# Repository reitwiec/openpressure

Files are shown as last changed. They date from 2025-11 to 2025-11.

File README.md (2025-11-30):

# Open Pressure Sensing Device

Reitwiec Shandilya, Michelle Hui, Sebastian Bidegain, Joey Castillo (Cornell Tech). Carson Gundlach and Dr. David Otterburn (Weill Cornell Medicine)

A handheld, open-source instrument designed to measure tactile pressure thresholds digitally. Adapted from clinical tools like the AcroVal™ system, it applies calibrated pressure to the skin and records sensory responses for studies of nerve regeneration following reconstructive surgery.

This project supports the ongoing research of Dr. David Otterburn and Carson Gundlach at Weill Cornell Medicine, whose work in neurotization seeks to restore sensory nerve connections following breast reconstruction surgery. After mastectomy, patients often experience a loss of sensation that affects comfort, safety, and quality of life. Through surgical co-aptation of donor and recipient nerves, Dr. Otterburn’s team aims to re-establish sensory pathways; however, evaluating the success of that process has long relied on subjective or coarse analog tools.
Developed by Cornell Tech Master’s students Michelle Hui and Reitwiec Shandilya in the Cornell Tech MakerLab, this open-source device captures quantitative measurements of tactile pressure (in g/mm²). By precisely logging patient response data, it allows clinicians to objectively track sensory recovery over time, providing richer, reproducible data than traditional Semmes-Weinstein monofilaments, which only measure at discrete force intervals. Beyond reconstructive surgery, the same sensing tool could inform other clinical neurological testing and research functions, expanding open-source tools for quantifying sensation and nerve function.

The project is supported by the Cornell Tech MakerLab and is undertaken in partnership with the Open Source Hardware Association’s Open Healthware Initiative, with the support of the National Science Foundation. The goal is to create a validated, open-source alternative to proprietary devices such as the AcroVal™ Neurosensory & Motor Testing System, enabling wider adoption of transparent, reproducible clinical instrumentation across research and education.

  

## Features

- **Real-time pressure readings** via USB serial connection
- **Session management** - Create, view, and export patient sessions
- **5 readings per session** with ability to re-record any reading
- **Historical trend visualization** - Track pressure changes across sessions
- **Device calibration** - Built-in calibration workflow
- **CSV export** - Export sessions for external analysis
- **Offline operation** - All data stored locally

## Prerequisites

### Hardware
- KB2040 microcontroller (or compatible CircuitPython board)
- HX711 load cell amplifier
- Load cell sensor
- USB cable

### Software
- Node.js 18+ and npm
- macOS (for building the Mac app)

## Installation

### For Development

```bash
# Clone or copy the project
cd pressure-monitor

# Install dependencies
npm install

# Run in development mode
npm run dev
```

### Building for Distribution

```bash
# Build the Mac application
npm run build:mac

# The installer will be in the `release` folder
```

The build creates:
- `Pressure Monitor-1.0.0.dmg` - Drag-and-drop installer
- `Pressure Monitor-1.0.0-mac.zip` - Portable version

## Firmware Setup

Copy both files from the `firmware/` folder to your KB2040:

```
firmware/
├── code.py      # Main firmware (runs automatically)
└── hx711.py     # HX711 driver library
```

### Installation
1. Connect your KB2040 via USB
2. It should appear as a drive called `CIRCUITPY`
3. Copy `code.py` and `hx711.py` to the root of that drive
4. The device will automatically restart and begin running

### Pin Configuration (in code.py)
- `DT_PIN = board.GP5` - HX711 Data
- `SCK_PIN = board.GP6` - HX711 Clock  
- `BTN_PIN = board.GP16` - Button (uses internal pull-up)

## Usage

### 1. Connect the Device
1. Plug in the KB2040 via USB
2. Open Pressure Monitor
3. Select the serial port from the right panel
4. Click to connect

### 2. Calibration (First Time Setup)
1. Click "Calibrate" in the top bar
2. Long-press the device button (≥0.7 seconds) to start
3. Follow the on-screen steps:
   - Remove all load and press button
   - Place calibration mass and press button
4. Calibration is saved until device restart

### 3. Taking Readings
1. Create a new session (add optional notes)
2. Press the device button to take a reading
3. Click on an empty slot to save the reading
4. Repeat until all 5 slots are filled

### 4. Viewing History
1. Click "History" in the sidebar
2. View trend graph of average readings across sessions
3. Toggle between stress (g/mm²) and weight (g) views

### 5. Exporting Data
1. Select a session
2. Click "Export CSV" in the top bar
3. Choose save location

## Data Storage

All data is stored in `~/PressureReadings/`:
- `session_[timestamp].csv` - Reading data
- `session_[timestamp]_meta.json` - Session metadata

CSV format:
```csv
slot,timestamp,grams,stress_g_mm2
1,2025-01-15T14:30:05,45.2,117.5
2,2025-01-15T14:30:45,44.8,116.4
...
```

## Configuration

Settings are available in the connection panel:
- **Wire Diameter (mm)** - Used for stress calculation
- **Calibration Mass (g)** - Reference mass for calibration

## Troubleshooting

### Device not showing up
- Ensure the KB2040 is properly connected
- Try a different USB cable
- Check if CircuitPython is running (should show as a serial device)

### Readings not appearing
- Verify the serial connection is established (green indicator)
- Check the Device Log for error messages
- Ensure the firmware is running correctly

### Calibration issues
- Make sure to remove ALL load during tare
- Use a precise calibration mass
- Keep the sensor stable during calibration

## License

MIT License - See LICENSE file for details.

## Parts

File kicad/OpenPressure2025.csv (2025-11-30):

Designator | Qty | Value | Exclude from BOM | Footprint | LCSC
R5 | 1 | 20K |  | Resistor_SMD:R_0805_2012Metric | C4328
Q2 | 1 | SS8550 |  | Package_TO_SOT_SMD:SOT-23 | C8542
C4,C6 | 2 | 10uF |  | Capacitor_SMD:C_0805_2012Metric | C15850
R1,R2,R3,R4 | 4 | 100 |  | Resistor_SMD:R_0805_2012Metric | C17408
R7 | 1 | 10K |  | Resistor_SMD:R_0805_2012Metric | C17414
R6 | 1 | 8.2K |  | Resistor_SMD:R_0805_2012Metric | C17828
C1,C2,C3,C5,C7 | 5 | 0.1uF |  | Capacitor_SMD:C_0805_2012Metric | C49678
L1 | 1 | 3.3uH |  | Inductor_SMD:L_0603_1608Metric | C275346
J2 | 1 | MJ-3523-SMT-TR |  | CUI_MJ-3523:CUI_MJ-3523-SMT-TR | C4992553
U2 | 1 | HX711 |  | Package_SO:SOIC-16_3.9x9.9mm_P1.27mm | C6705483

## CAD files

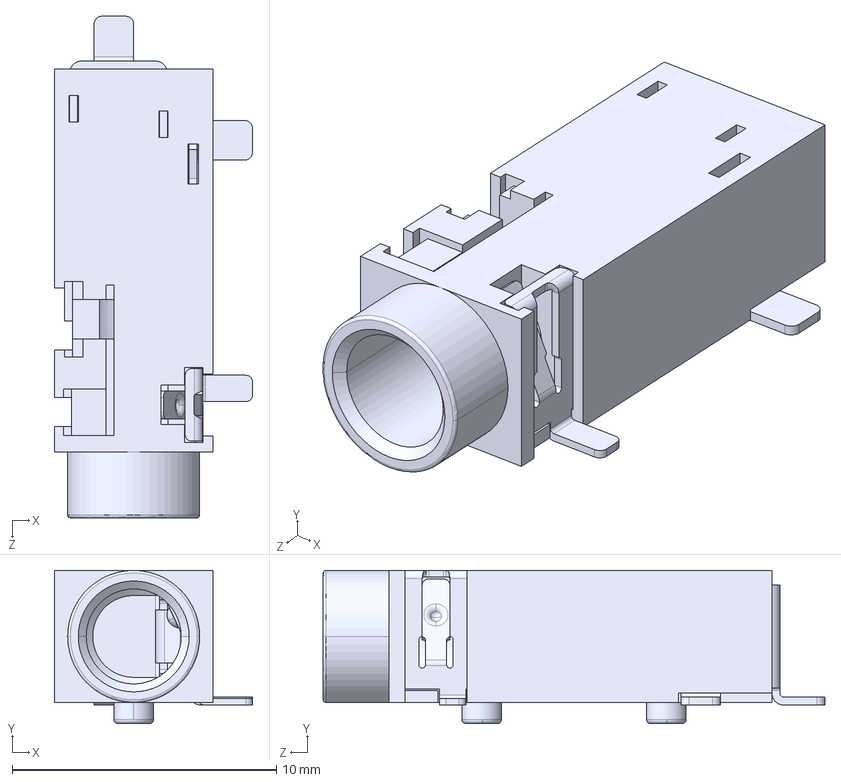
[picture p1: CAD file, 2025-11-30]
kicad/MJ-3523-SMT-TR.step
7.50 x 5.80 x 19.0 mm

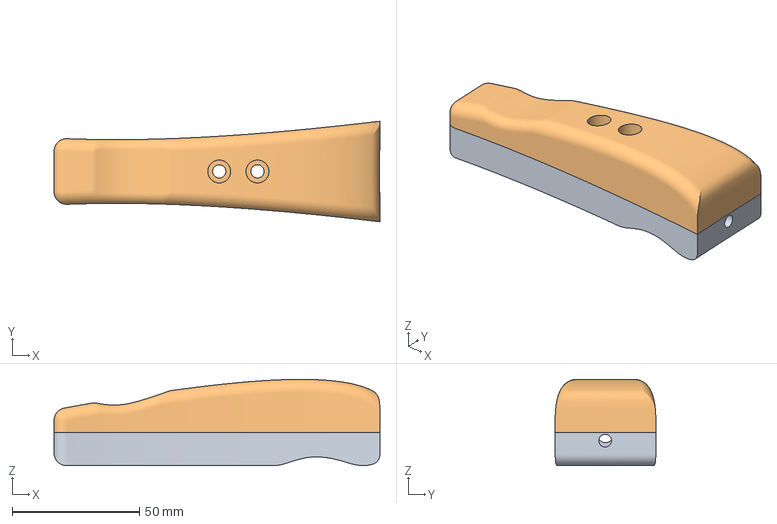
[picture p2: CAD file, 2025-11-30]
V0 openpressure.3mf
128.1 x 39.5 x 33.9 mm
BOTTOM Shell
TOP SHELL

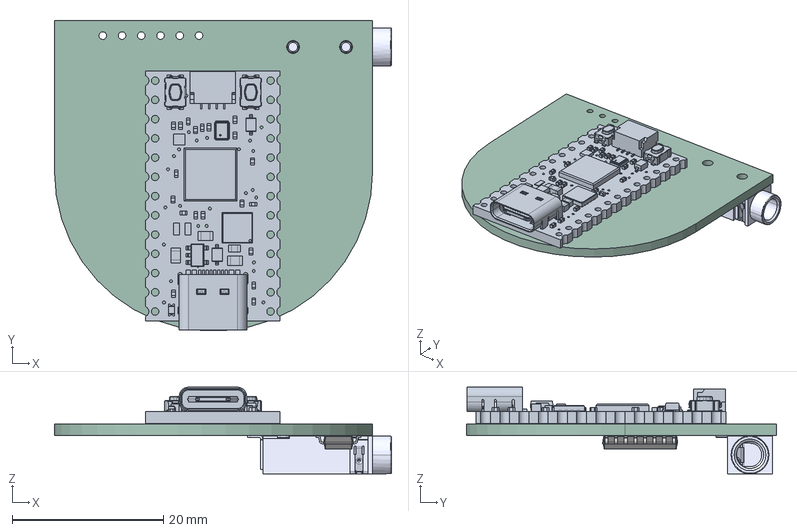
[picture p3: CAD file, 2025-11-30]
kicad/OpenPressureTest.step
44.5 x 40.9 x 11.4 mm
OpenPressureTest 1.1.1
MJ-3523-SMT-TR
SOIC-16_3.9x9.9mm_P1.27mm
OpenPressureTest_PCB

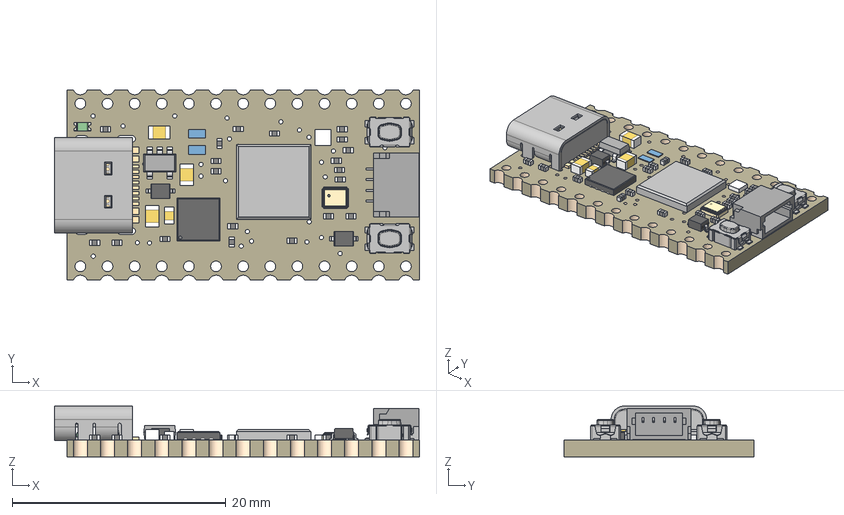
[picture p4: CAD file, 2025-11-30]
kicad/5302 KB2040.step
34.2 x 17.8 x 4.77 mm
Board
10µF x 2
AP2112K-3.3
KMR2 x 2
10K x 20
WS2812B_SK6805_1515
NSR0320 x 2
8MB QSPI Flash
1uF x 2
RP2040_QFN56
12MHZ
1uF_1
USB TYPE C
FUSE
STEMMA_I2C_QTSKINNY
GREEN

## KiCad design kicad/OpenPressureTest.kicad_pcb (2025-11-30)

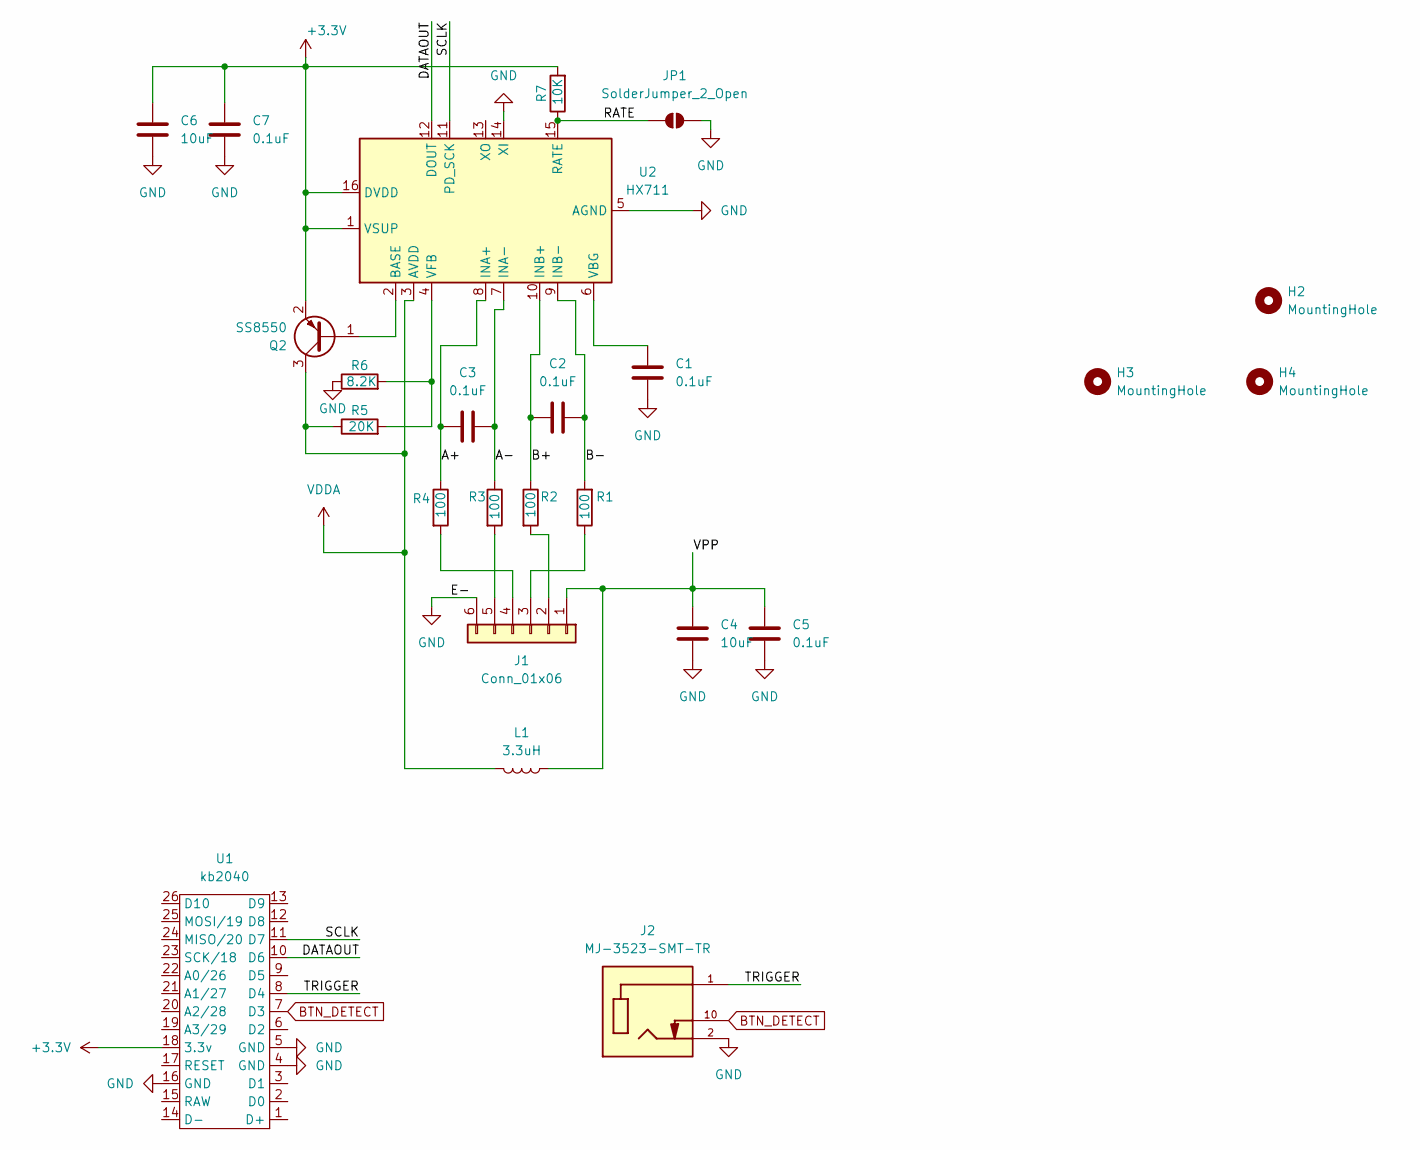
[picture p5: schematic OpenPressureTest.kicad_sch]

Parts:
C1, C2, C3, C5, C7: 0.1uF; C_0805_2012Metric; LCSC Part C49678
C4, C6: 10uF; C_0805_2012Metric; LCSC Part C15850
H2, H3, H4: MountingHole; MountingHole_2.2mm_M2
J1: Conn_01x06; PinHeader_1x06_P2.54mm_Vertical
J2: MJ-3523-SMT-TR; CUI_MJ-3523-SMT-TR; PARTREV 1.04; LCSC Part C4992553
JP1: SolderJumper_2_Open; SolderJumper-2_P1.3mm_Open_TrianglePad1.0x1.5mm
L1: 3.3uH; L_0603_1608Metric; LCSC Part C275346
Q2: SS8550; SOT-23; LCSC Part C8542
R1, R2, R3, R4: 100; R_0805_2012Metric; LCSC Part C17408
R5: 20K; R_0805_2012Metric; LCSC Part C4328
R6: 8.2K; R_0805_2012Metric; LCSC Part C17828
R7: 10K; R_0805_2012Metric; LCSC Part C17414
U1: kb2040; kb2040_SMT
U2: HX711; SOIC-16_3.9x9.9mm_P1.27mm; LCSC Part C6705483

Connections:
+3.3V: C6.1, C7.1, Q2.2 (E), R7.2, U1.18 (3.3v), U2.1 (VSUP), U2.16 (DVDD)
/A+: C3.1, R4.1, U2.8 (INA+)
/A-: C3.2, R3.1, U2.7 (INA-)
/B+: C2.1, R2.1, U2.10 (INB+)
/B-: C2.2, R1.2, U2.9 (INB-)
/DATAOUT: U1.10 (D6), U2.12 (DOUT)
/RATE: JP1.1 (A), R7.1, U2.15 (RATE)
/SCLK: U1.11 (D7), U2.11 (PD_SCK)
/TRIGGER: J2.1, U1.8 (D4)
/VPP: C4.1, C5.1, J1.1, L1.1
BTN_DETECT: J2.10, U1.7 (D3)
GND: C1.2, C4.2, C5.2, C6.2, C7.2, J1.6, J2.2, JP1.2 (B), R6.1, U1.4 (GND), U1.5 (GND), U1.16 (GND), U2.5 (AGND), U2.14 (XI)
unnamed: J1.2, R2.2
unnamed: J1.3, R1.1
unnamed: J1.4, R4.2
unnamed: J1.5, R3.2
unnamed: Q2.1 (B), U2.2 (BASE)
unnamed: C1.1, U2.6 (VBG)
unnamed: R5.2, R6.2, U2.4 (VFB)
VDDA: L1.2, Q2.3 (C), R5.1, U2.3 (AVDD)

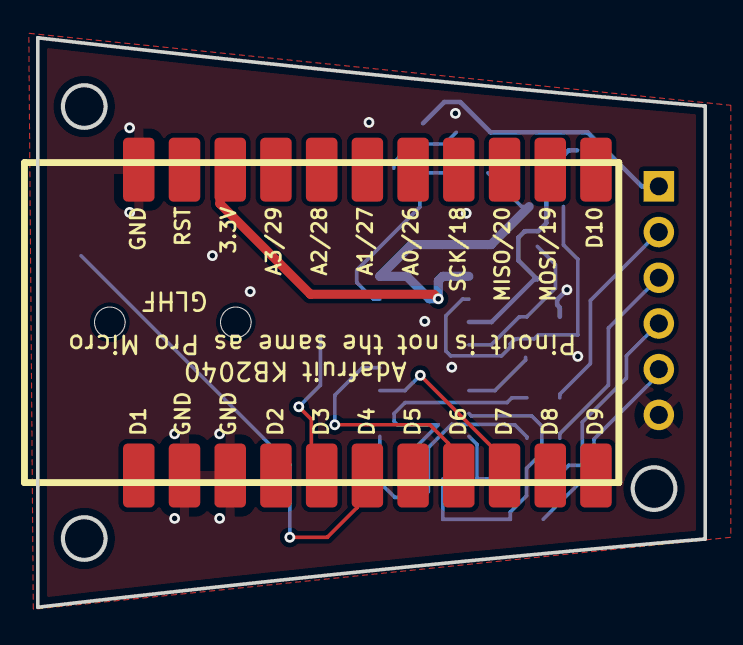
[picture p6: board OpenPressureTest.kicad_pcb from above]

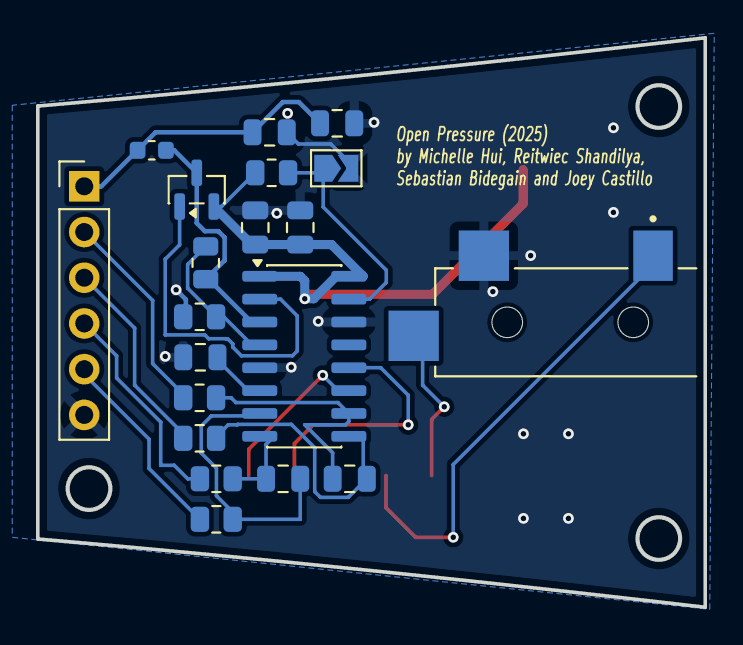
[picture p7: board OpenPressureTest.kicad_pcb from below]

Board: 4 copper layers, 37.1 x 31.6 mm, 24 parts (20 on the bottom side), 20 nets.

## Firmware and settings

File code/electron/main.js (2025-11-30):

const { app, BrowserWindow, ipcMain, dialog } = require('electron');
const path = require('path');
const fs = require('fs');
const { SerialPort } = require('serialport');
const { ReadlineParser } = require('@serialport/parser-readline');
const { parse } = require('csv-parse/sync');
const { stringify } = require('csv-stringify/sync');

let mainWindow;
let serialPort = null;
let parser = null;

// Data directory
const DATA_DIR = path.join(app.getPath('home'), 'PressureReadings');

function ensureDataDir() {
  if (!fs.existsSync(DATA_DIR)) {
    fs.mkdirSync(DATA_DIR, { recursive: true });
  }
}

// Path helpers
function getUserDir(userId) {
  return path.join(DATA_DIR, userId);
}

function getBodyPartDir(userId, bodyPartId) {
  return path.join(getUserDir(userId), bodyPartId);
}

function ensureUserDir(userId) {
  const userDir = getUserDir(userId);
  if (!fs.existsSync(userDir)) {
    fs.mkdirSync(userDir, { recursive: true });
  }
  return userDir;
}

function ensureBodyPartDir(userId, bodyPartId) {
  const dir = getBodyPartDir(userId, bodyPartId);
  if (!fs.existsSync(dir)) {
    fs.mkdirSync(dir, { recursive: true });
  }
  return dir;
}

function getSessionFilePath(userId, bodyPartId, sessionId) {
  return path.join(getBodyPartDir(userId, bodyPartId), `session_${sessionId}.csv`);
}

function getSessionMetaFilePath(userId, bodyPartId, sessionId) {
  return path.join(getBodyPartDir(userId, bodyPartId), `session_${sessionId}_meta.json`);
}

function createWindow() {
  mainWindow = new BrowserWindow({
    width: 1400,
    height: 900,
    minWidth: 1100,
    minHeight: 700,
    webPreferences: {
      nodeIntegration: false,
      contextIsolation: true,
      preload: path.join(__dirname, 'preload.js'),
    },
    titleBarStyle: 'hiddenInset',
    backgroundColor: '#0a0f1a',
    show: false,
  });

  if (process.env.NODE_ENV === 'development' || !app.isPackaged) {
    mainWindow.loadURL('http://localhost:5173');
    mainWindow.webContents.openDevTools();
  } else {
    mainWindow.loadFile(path.join(__dirname, '../dist/index.html'));
  }

  mainWindow.once('ready-to-show', () => {
    mainWindow.show();
  });

  mainWindow.on('closed', () => {
    mainWindow = null;
    if (serialPort && serialPort.isOpen) {
      serialPort.close();
    }
  });
}

app.whenReady().then(() => {
  ensureDataDir();
  createWindow();
});

app.on('window-all-closed', () => {
  if (process.platform !== 'darwin') {
    app.quit();
  }
});

app.on('activate', () => {
  if (BrowserWindow.getAllWindows().length === 0) {
    createWindow();
  }
});

// ==================== Serial Port Handlers ====================

ipcMain.handle('serial:list', async () => {
  try {
    const ports = await SerialPort.list();
    return ports.filter(p => 
      p.vendorId || p.manufacturer || p.serialNumber
    ).map(p => ({
      path: p.path,
      manufacturer: p.manufacturer || 'Unknown',
      vendorId: p.vendorId,
      productId: p.productId,
    }));
  } catch (error) {
    console.error('Error listing ports:', error);
    return [];
  }
});

ipcMain.handle('serial:connect', async (event, portPath) => {
  try {
    if (serialPort) {
      try {
        if (serialPort.isOpen) {
          await new Promise((resolve, reject) => {
            serialPort.close((err) => {
              if (err) reject(err);
              else resolve();
            });
          });
        }
      } catch (closeErr) {
        console.log('Error closing existing port:', closeErr.message);
      }
      serialPort = null;
      parser = null;
    }

    await new Promise(resolve => setTimeout(resolve, 100));

    serialPort = new SerialPort({
      path: portPath,
      baudRate: 115200,
    });

    parser = serialPort.pipe(new ReadlineParser({ delimiter: '\n' }));

    parser.on('data', (line) => {
      const trimmed = line.trim();
      console.log('Serial:', trimmed);
      
      if (trimmed.startsWith('>>> SNAPSHOT:')) {
        const match = trimmed.match(/SNAPSHOT:\s*([\d.]+)\s*g,\s*([\d.]+)\s*g\/mm/);
        if (match) {
          mainWindow?.webContents.send('serial:reading', {
            grams: parseFloat(match[1]),
            stress: parseFloat(match[2]),
            timestamp: new Date().toISOString(),
          });
        }
      }
      
      if (trimmed.includes('CALIBRATION')) {
        mainWindow?.webContents.send('serial:calibration', { status: 'started' });
      }
      if (trimmed.includes('Tare done')) {
        mainWindow?.webContents.send('serial:calibration', { status: 'tared' });
      }
      if (trimmed.includes('NEW REFERENCE_UNIT')) {
        const match = trimmed.match(/NEW REFERENCE_UNIT:\s*([\d.]+)/);
        mainWindow?.webContents.send('serial:calibration', { 
          status: 'complete',
          referenceUnit: match ? parseFloat(match[1]) : null,
        });
      }
      if (trimmed.includes('Verification reading')) {
        const match = trimmed.match(/Verification reading:\s*([\d.]+)/);
        mainWindow?.webContents.send('serial:calibration', {
          status: 'verified',
          verificationGrams: match ? parseFloat(match[1]) : null,
        });
      }
      
      mainWindow?.webContents.send('serial:message', trimmed);
    });

    serialPort.on('error', (err) => {
      console.error('Serial error:', err);
      mainWindow?.webContents.send('serial:error', err.message);
    });

    serialPort.on('close', () => {
      mainWindow?.webContents.send('serial:disconnected');
    });

    return { success: true };
  } catch (error) {
    console.error('Connection error:', error);
    return { success: false, error: error.message };
  }
});

ipcMain.handle('serial:disconnect', async () => {
  try {
    if (serialPort) {
      if (serialPort.isOpen) {
        await new Promise((resolve, reject) => {
          serialPort.close((err) => {
            if (err) reject(err);
            else resolve();
          });
        });
      }
      serialPort = null;
      parser = null;
    }
    return { success: true };
  } catch (error) {
    console.error('Disconnect error:', error);
    serialPort = null;
    parser = null;
    return { success: true };
  }
});

ipcMain.handle('serial:send', async (event, command) => {
  try {
    if (serialPort && serialPort.isOpen) {
      serialPort.write(command + '\n');
      return { success: true };
    }
    return { success: false, error: 'Port not open' };
  } catch (error) {
    return { success: false, error: error.message };
  }
});

ipcMain.handle('serial:isConnected', () => {
  return !!(serialPort && serialPort.isOpen);
});

app.on('browser-window-created', (event, window) => {
  window.webContents.on('did-start-loading', async () => {
    if (serialPort && serialPort.isOpen) {
      console.log('Window reloading - closing serial port');
      try {
        await new Promise((resolve) => {
          serialPort.close(() => resolve());
        });
      } catch (err) {
        console.log('Error closing port on reload:', err.message);
      }
      serialPort = null;
      parser = null;
    }
  });
});

// ==================== User Handlers ====================

ipcMain.handle('user:list', async () => {
  try {
    ensureDataDir();
    const entries = fs.readdirSync(DATA_DIR, { withFileTypes: true });
    const users = entries
      .filter(e => e.isDirectory())
      .map(e => {
        const userDir = path.join(DATA_DIR, e.name);
        const metaPath = path.join(userDir, 'user_meta.json');
        let meta = { name: e.name };
        if (fs.existsSync(metaPath)) {
          try {
            meta = JSON.parse(fs.readFileSync(metaPath, 'utf-8'));
          } catch (err) {
            console.error('Error reading user meta:', err);
          }
        }
        
        // Count body parts
        const bodyPartCount = fs.readdirSync(userDir, { withFileTypes: true })
          .filter(f => f.isDirectory()).length;
        
        return {
          id: e.name,
          name: meta.name || e.name,
          notes: meta.notes || '',
          created: meta.created || null,
          bodyPartCount,
        };
      });
    
    return users.sort((a, b) => (a.name || '').localeCompare(b.name || ''));
  } catch (error) {
    console.error('Error listing users:', error);
    return [];
  }
});

ipcMain.handle('user:create', async (event, { name, notes }) => {
  try {
    ensureDataDir();
    const id = name.replace(/[^a-zA-Z0-9\s-]/g, '').replace(/\s+/g, '_').substring(0, 50) + '_' + Date.now();
    const userDir = ensureUserDir(id);
    
    const meta = {
      name,
      notes: notes || '',
      created: new Date().toISOString(),
    };
    
    fs.writeFileSync(path.join(userDir, 'user_meta.json'), JSON.stringify(meta, null, 2));
    
    return { success: true, userId: id, meta };
  } catch (error) {
    console.error('Error creating user:', error);
    return { success: false, error: error.message };
  }
});

ipcMain.handle('user:get', async (event, userId) => {
  try {
    const userDir = getUserDir(userId);
    const metaPath = path.join(userDir, 'user_meta.json');
    
    if (!fs.existsSync(metaPath)) {
      return { success: false, error: 'User not found' };
    }
    
    const meta = JSON.parse(fs.readFileSync(metaPath, 'utf-8'));
    
    return { success: true, user: { id: userId, ...meta } };
  } catch (error) {
    console.error('Error getting user:', error);
    return { success: false, error: error.message };
  }
});

ipcMain.handle('user:update', async (event, { userId, name, notes }) => {
  try {
    const userDir = getUserDir(userId);
    const metaPath = path.join(userDir, 'user_meta.json');
    
    if (!fs.existsSync(metaPath)) {
      return { success: false, error: 'User not found' };
    }
    
    const meta = JSON.parse(fs.readFileSync(metaPath, 'utf-8'));
    if (name !== undefined) meta.name = name;
    if (notes !== undefined) meta.notes = notes;
    
    fs.writeFileSync(metaPath, JSON.stringify(meta, null, 2));
    
    return { success: true };
  } catch (error) {
    console.error('Error updating user:', error);
    return { success: false, error: error.message };
  }
});

ipcMain.handle('user:delete', async (event, userId) => {
  try {
    const userDir = getUserDir(userId);
    if (fs.existsSync(userDir)) {
      fs.rmSync(userDir, { recursive: true });
    }
    return { success: true };
  } catch (error) {
    console.error('Error deleting user:', error);
    return { success: false, error: error.message };
  }
});

// ==================== Body Part Handlers ====================

ipcMain.handle('bodyPart:list', async (event, userId) => {
  try {
    if (!userId) return [];
    
    const userDir = getUserDir(userId);
    if (!fs.existsSync(userDir)) return [];
    
    const entries = fs.readdirSync(userDir, { withFileTypes: true });
    const bodyParts = entries
      .filter(e => e.isDirectory())
      .map(e => {
        const bpDir = path.join(userDir, e.name);
        const metaPath = path.join(bpDir, 'bodypart_meta.json');
        let meta = { label: e.name };
        if (fs.existsSync(metaPath)) {
          try {
            meta = JSON.parse(fs.readFileSync(metaPath, 'utf-8'));
          } catch (err) {
            console.error('Error reading body part meta:', err);
          }
        }
        
        // Count sessions
        const sessionCount = fs.readdirSync(bpDir)
          .filter(f => f.endsWith('_meta.json') && f.startsWith('session_')).length;
        
        return {
          id: e.name,
          label: meta.label || e.name,
          notes: meta.notes || '',
          created: meta.created || null,
          sessionCount,
        };
      });
    
    return bodyParts.sort((a, b) => new Date(b.created || 0) - new Date(a.created || 0));
  } catch (error) {
    console.error('Error listing body parts:', error);
    return [];
  }
});

ipcMain.handle('bodyPart:create', async (event, { userId, label, notes }) => {
  try {
    if (!userId) return { success: false, error: 'No user selected' };
    
    ensureUserDir(userId);
    const id = label.replace(/[^a-zA-Z0-9\s-]/g, '').replace(/\s+/g, '_').substring(0, 50) + '_' + Date.now();
    const bpDir = ensureBodyPartDir(userId, id);
    
    const meta = {
      label,
      notes: notes || '',
      created: new Date().toISOString(),
    };
    
    fs.writeFileSync(path.join(bpDir, 'bodypart_meta.json'), JSON.stringify(meta, null, 2));
    
    return { success: true, bodyPartId: id, meta };
  } catch (error) {
    console.error('Error creating body part:', error);
    return { success: false, error: error.message };
  }
});

ipcMain.handle('bodyPart:get', async (event, { userId, bodyPartId }) => {
  try {
    if (!userId || !bodyPartId) return { success: false, error: 'Missing parameters' };
    
    const bpDir = getBodyPartDir(userId, bodyPartId);
    const metaPath = path.join(bpDir, 'bodypart_meta.json');
    
    if (!fs.existsSync(metaPath)) {
      return { success: false, error: 'Body part not found' };
    }
    
    const meta = JSON.parse(fs.readFileSync(metaPath, 'utf-8'));
    
    return { success: true, bodyPart: { id: bodyPartId, ...meta } };
  } catch (error) {
    console.error('Error getting body part:', error);
    return { success: false, error: error.message };
  }
});

ipcMain.handle('bodyPart:update', async (event, { userId, bodyPartId, label, notes }) => {
  try {
    if (!userId || !bodyPartId) return { success: false, error: 'Missing parameters' };
    
    const bpDir = getBodyPartDir(userId, bodyPartId);
    const metaPath = path.join(bpDir, 'bodypart_meta.json');
    
    if (!fs.existsSync(metaPath)) {
      return { success: false, error: 'Body part not found' };
    }
    
    const meta = JSON.parse(fs.readFileSync(metaPath, 'utf-8'));
    if (label !== undefined) meta.label = label;
    if (notes !== undefined) meta.notes = notes;
    
    fs.writeFileSync(metaPath, JSON.stringify(meta, null, 2));
    
    return { success: true };
  } catch (error) {
    console.error('Error updating body part:', error);
    return { success: false, error: error.message };
  }
});

ipcMain.handle('bodyPart:delete', async (event, { userId, bodyPartId }) => {
  try {
    if (!userId || !bodyPartId) return { success: false, error: 'Missing parameters' };
    
    const bpDir = getBodyPartDir(userId, bodyPartId);
    if (fs.existsSync(bpDir)) {
      fs.rmSync(bpDir, { recursive: true });
    }
    return { success: true };
  } catch (error) {
    console.error('Error deleting body part:', error);
    return { success: false, error: error.message };
  }
});

// ==================== Session Handlers ====================

ipcMain.handle('session:list', async (event, { userId, bodyPartId }) => {
  try {
    if (!userId || !bodyPartId) {
      console.log('session:list called with missing params');
      return [];
    }
    
    const bpDir = getBodyPartDir(userId, bodyPartId);
    if (!fs.existsSync(bpDir)) return [];
    
    const files = fs.readdirSync(bpDir);
    const metaFiles = files.filter(f => f.endsWith('_meta.json') && f.startsWith('session_'));
    
    const sessions = metaFiles.map(metaFile => {
      const sessionId = metaFile.replace('session_', '').replace('_meta.json', '');
      const metaPath = path.join(bpDir, metaFile);
      const csvPath = getSessionFilePath(userId, bodyPartId, sessionId);
      
      let meta = {};
      try {
        meta = JSON.parse(fs.readFileSync(metaPath, 'utf-8'));
      } catch (e) {
        console.error('Error reading meta:', e);
      }
      
      let readingsCount = 0;
      if (fs.existsSync(csvPath)) {
        const csvContent = fs.readFileSync(csvPath, 'utf-8');
        const records = parse(csvContent, { columns: true });
        readingsCount = records.length;
      }
      
      return {
        id: sessionId,
        ...meta,
        readingsCount,
      };
    });
    
    return sessions.sort((a, b) => new Date(b.created) - new Date(a.created));
  } catch (error) {
    console.error('Error listing sessions:', error);
    return [];
  }
});

ipcMain.handle('session:create', async (event, { userId, bodyPartId, notes, wireDiameter, calibrationMass }) => {
  try {
    if (!userId || !bodyPartId) {
      return { success: false, error: 'Missing user or body part' };
    }
    
    ensureBodyPartDir(userId, bodyPartId);
    const sessionId = new Date().toISOString().replace(/[:.]/g, '-');
    
    const meta = {
      created: new Date().toISOString(),
      notes: notes || '',
      wireDiameter: wireDiameter || 0.7,
      calibrationMass: calibrationMass || 41.0,
    };
    
    fs.writeFileSync(getSessionMetaFilePath(userId, bodyPartId, sessionId), JSON.stringify(meta, null, 2));
    
    const csvHeader = stringify([['slot', 'timestamp', 'grams', 'stress_g_mm2']], { header: false });
    fs.writeFileSync(getSessionFilePath(userId, bodyPartId, sessionId), csvHeader);
    
    return { success: true, sessionId, meta };
  } catch (error) {
    console.error('Error creating session:', error);
    return { success: false, error: error.message };
  }
});

ipcMain.handle('session:get', async (event, { userId, bodyPartId, sessionId }) => {
  try {
    if (!userId || !bodyPartId || !sessionId) {
      return { success: false, error: 'Missing parameters' };
    }
    
    const metaPath = getSessionMetaFilePath(userId, bodyPartId, sessionId);
    const csvPath = getSessionFilePath(userId, bodyPartId, sessionId);
    
    if (!fs.existsSync(metaPath)) {
      return { success: false, error: 'Session not found' };
    }
    
    const meta = JSON.parse(fs.readFileSync(metaPath, 'utf-8'));
    
    let readings = [];
    if (fs.existsSync(csvPath)) {
      const csvContent = fs.readFileSync(csvPath, 'utf-8');
      readings = parse(csvContent, { columns: true });
      readings = readings.map(r => ({
        slot: parseInt(r.slot),
        timestamp: r.timestamp,
        grams: parseFloat(r.grams),
        stress: parseFloat(r.stress_g_mm2),
      }));
    }
    
    return { success: true, session: { id: sessionId, ...meta, readings } };
  } catch (error) {
    console.error('Error getting session:', error);
    return { success: false, error: error.message };
  }
});

ipcMain.handle('session:addReading', async (event, { userId, bodyPartId, sessionId, slot, grams, stress }) => {
  try {
    if (!userId || !bodyPartId || !sessionId) {
      return { success: false, error: 'Missing parameters' };
    }
    
    const csvPath = getSessionFilePath(userId, bodyPartId, sessionId);
    
    if (!fs.existsSync(csvPath)) {
      return { success: false, error: 'Session not found' };
    }
    
    const csvContent = fs.readFileSync(csvPath, 'utf-8');
    let readings = parse(csvContent, { columns: true });
    
    readings = readings.filter(r => parseInt(r.slot) !== slot);
    
    readings.push({
      slot: slot.toString(),
      timestamp: new Date().toISOString(),
      grams: grams.toFixed(2),
      stress_g_mm2: stress.toFixed(3),
    });
    
    readings.sort((a, b) => parseInt(a.slot) - parseInt(b.slot));
    
    const output = stringify(readings, { header: true, columns: ['slot', 'timestamp', 'grams', 'stress_g_mm2'] });
    fs.writeFileSync(csvPath, output);
    
    return { success: true };
  } catch (error) {
    console.error('Error adding reading:', error);
    return { success: false, error: error.message };
  }
});

ipcMain.handle('session:deleteReading', async (event, { userId, bodyPartId, sessionId, slot }) => {
  try {
    if (!userId || !bodyPartId || !sessionId) {
      return { success: false, error: 'Missing parameters' };
    }
    
    const csvPath = getSessionFilePath(userId, bodyPartId, sessionId);
    
    if (!fs.existsSync(csvPath)) {
      return { success: false, error: 'Session not found' };
    }
    
    const csvContent = fs.readFileSync(csvPath, 'utf-8');
    let readings = parse(csvContent, { columns: true });
    
    readings = readings.filter(r => parseInt(r.slot) !== slot);
    
    const output = stringify(readings, { header: true, columns: ['slot', 'timestamp', 'grams', 'stress_g_mm2'] });
    fs.writeFileSync(csvPath, output);
    
    return { success: true };
  } catch (error) {
    console.error('Error deleting reading:', error);
    return { success: false, error: error.message };
  }
});

ipcMain.handle('session:updateNotes', async (event, { userId, bodyPartId, sessionId, notes }) => {
  try {
    if (!userId || !bodyPartId || !sessionId) {
      return { success: false, error: 'Missing parameters' };
    }
    
    const metaPath = getSessionMetaFilePath(userId, bodyPartId, sessionId);
    
    if (!fs.existsSync(metaPath)) {
      return { success: false, error: 'Session not found' };
    }
    
    const meta = JSON.parse(fs.readFileSync(metaPath, 'utf-8'));
    meta.notes = notes;
    fs.writeFileSync(metaPath, JSON.stringify(meta, null, 2));
    
    return { success: true };
  } catch (error) {
    console.error('Error updating notes:', error);
    return { success: false, error: error.message };
  }
});

ipcMain.handle('session:delete', async (event, { userId, bodyPartId, sessionId }) => {
  try {
    if (!userId || !bodyPartId || !sessionId) {
      return { success: false, error: 'Missing parameters' };
    }
    
    const csvPath = getSessionFilePath(userId, bodyPartId, sessionId);
    const metaPath = getSessionMetaFilePath(userId, bodyPartId, sessionId);
    
    if (fs.existsSync(csvPath)) fs.unlinkSync(csvPath);
    if (fs.existsSync(metaPath)) fs.unlinkSync(metaPath);
    
    return { success: true };
  } catch (error) {
    console.error('Error deleting session:', error);
    return { success: false, error: error.message };
  }
});
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

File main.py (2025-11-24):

import board
import digitalio
import time
import sys
import math
from hx711 import HX711

# ------------------ Hardware / HX711 ------------------
DT_PIN = board.GP5
SCK_PIN = board.GP6
GAIN = 128
REFERENCE_UNIT = 6504   # placeholder; long-press recalculates

BTN_PIN = board.GP16
DEBOUNCE_MS = 40
LONGPRESS_MS = 700

# ------------------ Wire geometry ------------------
WIRE_DIAMETER_MM = 0.7  # round wire Ø (mm)

# ------------------ Calibration mass (grams) ------------------
CAL_MASS_G = 41.0

# ------------------ Internal state ------------------
_capture_requested = False
_last_irq_ms = 0
_pressed_since = None
_in_calib = False
_calib_step = 0
_calib_pre = None

def wire_area_mm2(d_mm):
    r = d_mm * 0.5
    return math.pi * r * r

def snapshot_weight_g(hx, n=12, inter_ms=4):
    vals = []
    for _ in range(n):
        vals.append(hx.get_weight(1))
        time.sleep(inter_ms / 1000.0)
    vals.sort()
    if len(vals) >= 5:
        vals = vals[1:-1]
    return sum(vals) / len(vals)

def snapshot_counts(hx, n=16, inter_ms=4):
    vals = []
    for _ in range(n):
        vals.append(hx.get_value(1))
        time.sleep(inter_ms / 1000.0)
    vals.sort()
    if len(vals) >= 5:
        vals = vals[1:-1]
    return sum(vals) / len(vals)

def clean_and_exit():
    print("Bye!")
    sys.exit()

def main():
    global _capture_requested, _pressed_since, _in_calib, _calib_step, _calib_pre, REFERENCE_UNIT

    area = wire_area_mm2(WIRE_DIAMETER_MM)
    if area <= 0:
        print("Invalid wire diameter/area.")
        sys.exit()

    hx = HX711(dout=DT_PIN, pd_sck=SCK_PIN, gain=GAIN)
    time.sleep(0.2)
    hx.set_reference_unit(REFERENCE_UNIT)

    print("Taring... remove any load.")
    hx.tare(20)
    print("Tare done.\n")

    btn = digitalio.DigitalInOut(BTN_PIN)
    btn.direction = digitalio.Direction.INPUT
    btn.pull = digitalio.Pull.UP

    print(f"Wire area: {area:.4f} mm²")
    print("Controls: short press = snapshot   |   long press (≥0.7s) = CALIBRATION\n")

    btn_prev = True
    
    try:
        while True:
            now = time.monotonic() * 1000  # Convert to milliseconds
            btn_current = btn.value
            
            # Detect button press (falling edge)
            if btn_prev and not btn_current:
                if now - _last_irq_ms > DEBOUNCE_MS:
                    _capture_requested = True
                    _last_irq_ms = now
                    if _pressed_since is None:
                        _pressed_since = now
            
            btn_prev = btn_current
            
            if _pressed_since is not None:
                if not btn_current and (now - _pressed_since) >= LONGPRESS_MS and not _in_calib:
                    _capture_requested = False
                    _pressed_since = None
                    _in_calib = True
                    _calib_step = 0
                    _calib_pre = None

                    print("\n=== CALIBRATION ===")
                    print("Step 1/3: Removing load and taring...")
                    hx.set_reference_unit(1)
                    hx.tare(25)
                    print("Tare done.")
                    print("Step 2/3: Ensure NO LOAD is on the cell, then press the button.")
                elif btn_current:
                    _pressed_since = None

            if _capture_requested:
                _capture_requested = False
                if _in_calib:
                    if _calib_step == 0:
                        _calib_pre = snapshot_counts(hx)
                        print(f"Captured zero-load counts: {_calib_pre:.0f}")
                        print(f"Step 3/3: Place {CAL_MASS_G:.3f} g on the cell, then press the button.")
                        _calib_step = 1
                    elif _calib_step == 1:
                        post = snapshot_counts(hx)
                        delta = abs(post - _calib_pre)
                        if CAL_MASS_G > 0:
                            ru = delta / CAL_MASS_G
                            REFERENCE_UNIT = ru
                            hx.set_reference_unit(REFERENCE_UNIT)
                            print(f"Captured loaded counts: {post:.0f}")
                            print(f"Δ counts: {delta:.0f}")
                            print(f"NEW REFERENCE_UNIT: {REFERENCE_UNIT:.2f} counts/g")
                            g_check = snapshot_weight_g(hx, n=8)
                            print(f"Verification reading: {g_check:.2f} g")
                        print("Calibration complete.\n")
                        _in_calib = False
                        _calib_step = 0
                        _calib_pre = None
                else:
                    snap_g = abs(snapshot_weight_g(hx))
                    snap_stress = snap_g / area
                    print(f">>> SNAPSHOT: {snap_g:.2f} g, {snap_stress:.3f} g/mm²")

            time.sleep(0.03)

    except KeyboardInterrupt:
        clean_and_exit()

if __name__ == "__main__":
    main()
